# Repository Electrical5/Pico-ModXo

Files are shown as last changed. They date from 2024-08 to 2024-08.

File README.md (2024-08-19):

# Pi Pico modchip adapter for Original Xbox

This version is based on the ['V1 version'](https://github.com/Team-Resurgent/Modxo) by Team Resurgent (including Shalx)

See the [V0.2 release](https://github.com/Electrical5/Pico-ModXo/releases/tag/V0.2) for the support of the original "[ModXo](https://github.com/shalxmva/modxo)" by Shalx

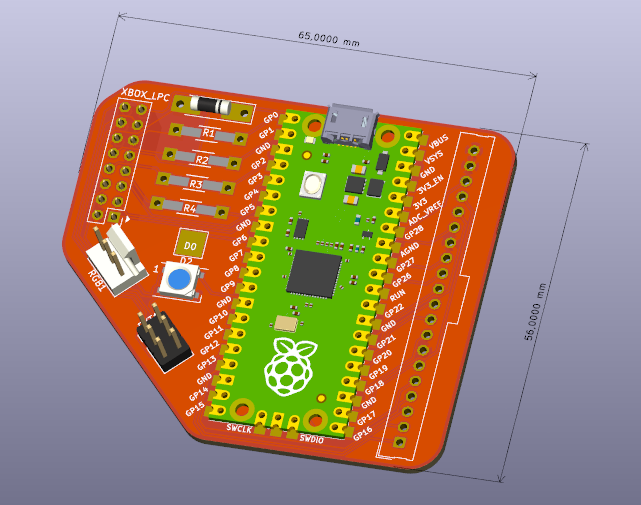
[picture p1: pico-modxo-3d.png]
3d


# Easy to solder

All components can be soldered 'though hole' at home and the Pico/resistors also have 'surface mount' options, making it ideal for hobbyists or mass production.

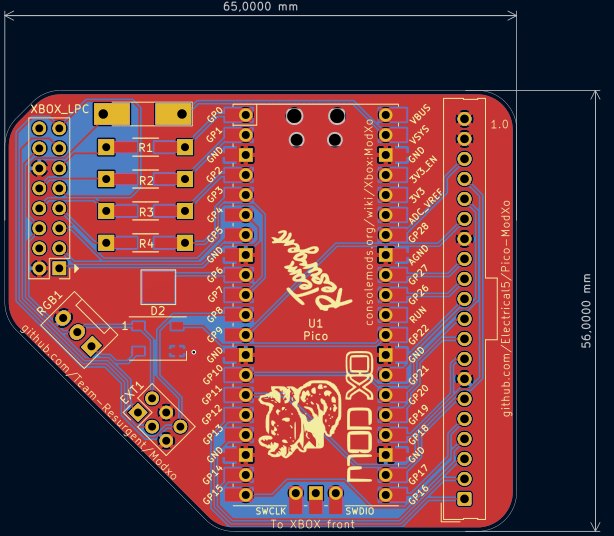
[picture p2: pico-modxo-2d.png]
2d


# Fully open source

The KiCad (free application) source files (full schematics!) are included, so you can add/remove components based on your preferences.

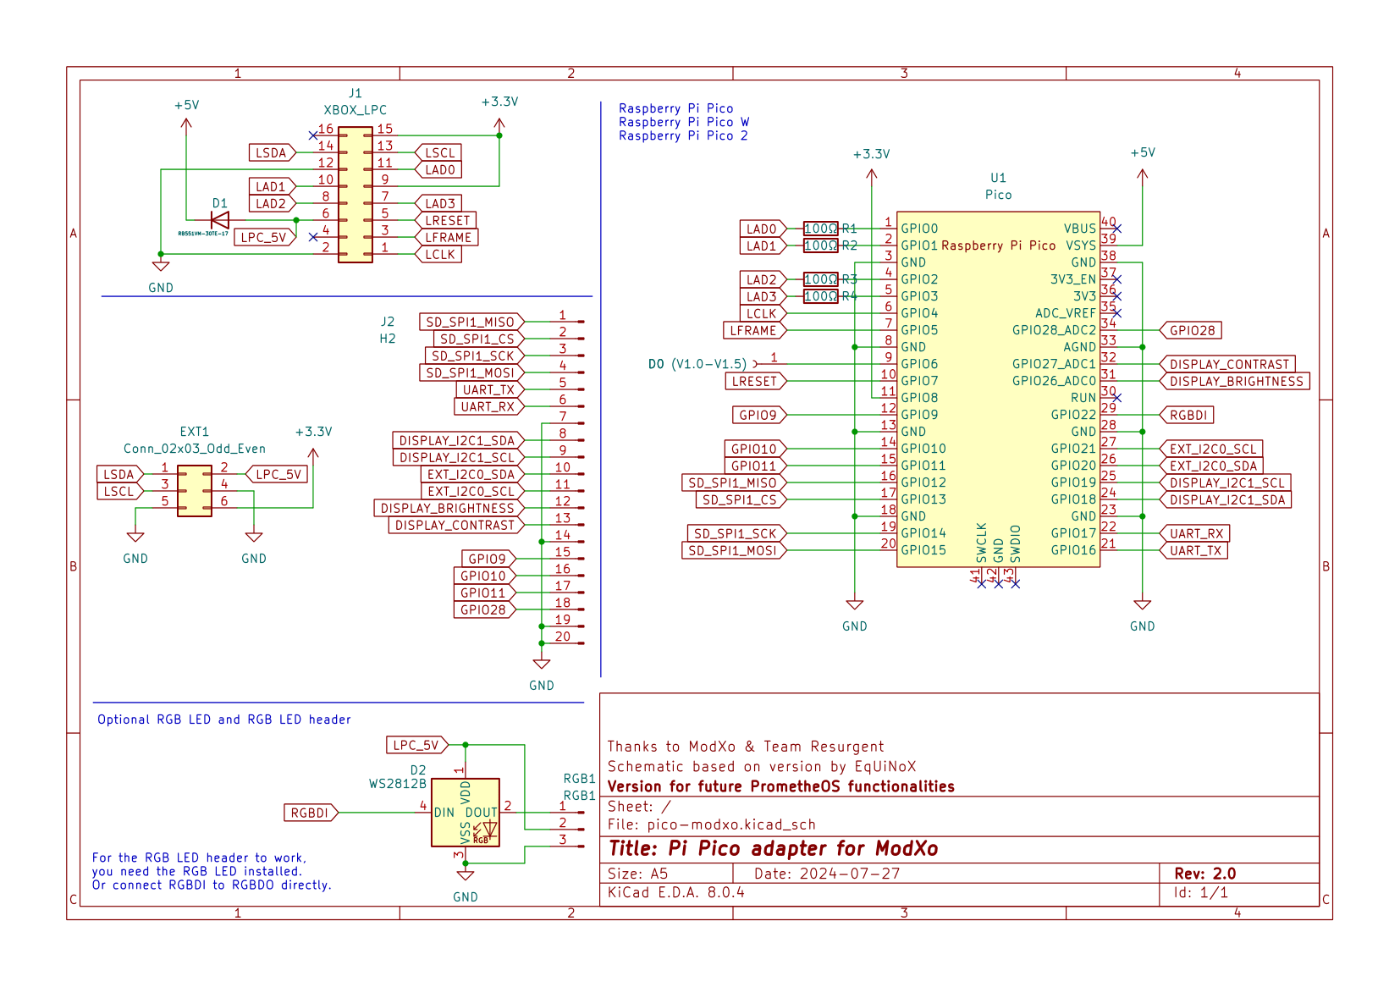
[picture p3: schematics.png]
schematics


# SMBus

Currently ModXo doesn't implement reading SMBus via I2C, in the future this could add functionality such as monitoring temperature/fanspeed, LED control or restarting/shutdown the xbox remotely.
Especially if paired with the Pi Pico Wireless, it could allow basic remote control / monitoring of the xbox.
However, there's two solder jumpers to connect the SMBus of the Xbox to the Pi Pico.

# License

GNU GENERAL PUBLIC LICENSE
Version 3, 29 June 2007

You can sell this board as-is, but disclose the source.
If you sell modifications of this board (additional headers for LED strips / LCD / fan), share the modifications / source files under the same license.

# More info

https://github.com/shalxmva/modxo
https://consolemods.org/wiki/Xbox:ModXo

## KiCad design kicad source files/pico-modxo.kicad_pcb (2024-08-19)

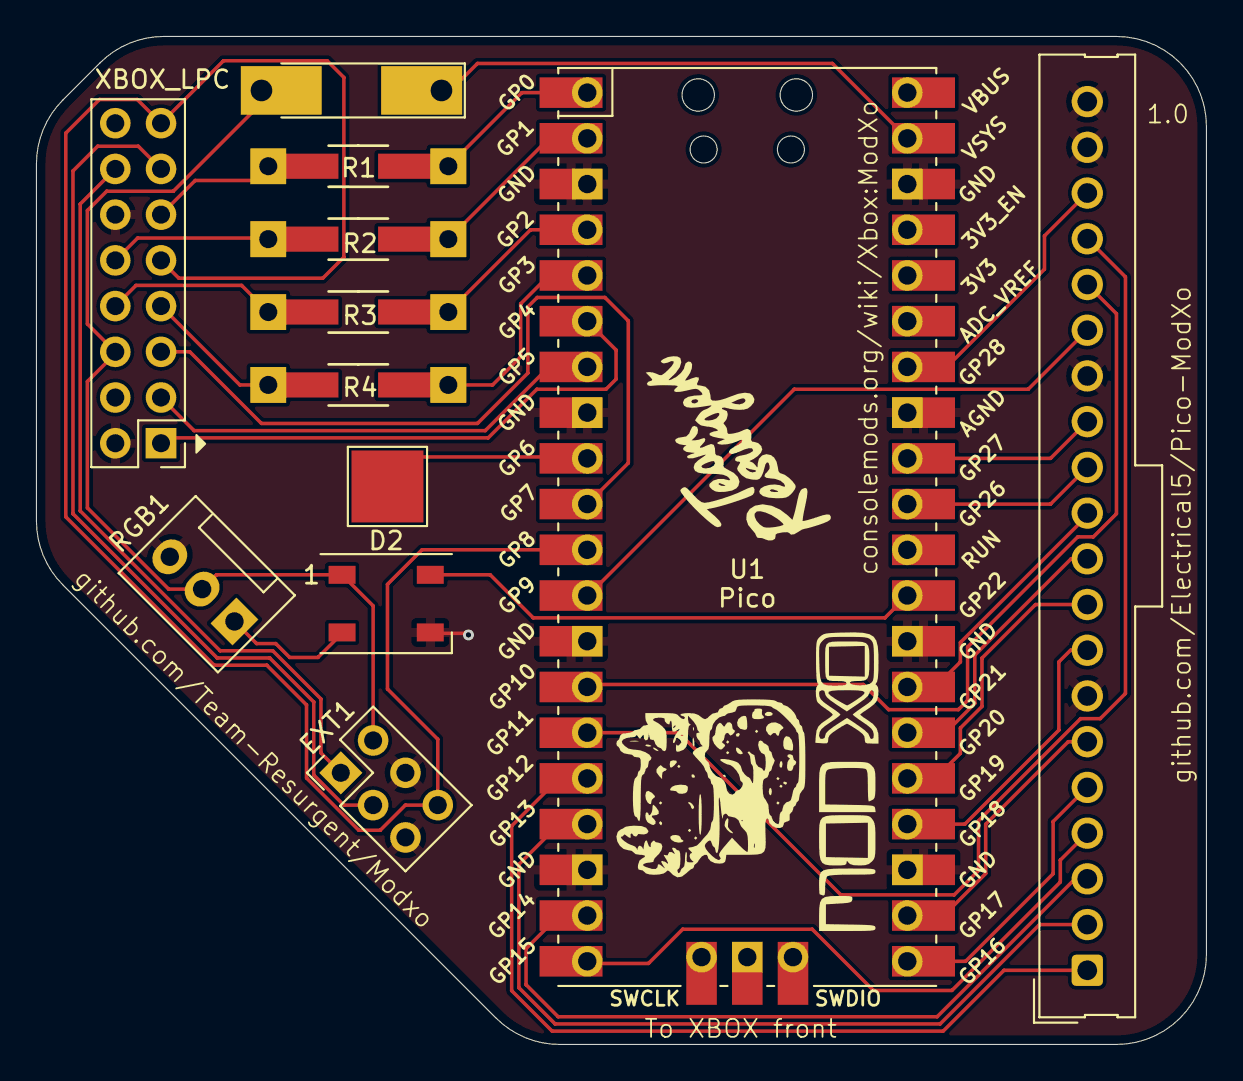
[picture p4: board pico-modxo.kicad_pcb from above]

Board: 2 copper layers, 65.0 x 56.0 mm, 12 parts (0 on the bottom side), 36 nets.

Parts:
D0: D0 (V1.0-V1.5); TestPoint_Pad_4.0x4.0mm
D1: RB551VM-30TE-17; D_MELF-RM10_Universal_Handsoldering
D2: WS2812B; LED_WS2812B_PLCC4_5.0x5.0mm_P3.2mm
EXT1: Conn_02x03_Odd_Even; PinHeader_2x03_P2.54mm_Vertical
J1: XBOX_LPC; xbox_lpc
J2: H2; Molex_SL_171971-0020_1x20_P2.54mm_Vertical
R1, R2, R3, R4: 100Ω; Resistor_SMD+THTuniversal_1206_RM10_HandSoldering
RGB1: RGB1; FanPinHeader_1x03_P2.54mm_Vertical
U1: Pico; RPi_Pico_SMD_TH

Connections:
+3.3V: EXT1.6, J1.9 (3.3V), J1.15 (3.3V), U1.11 (GPIO8)
+5V: D1.1 (K), U1.39 (VSYS)
DISPLAY_BRIGHTNESS: J2.12, U1.31 (GPIO26_ADC0)
DISPLAY_CONTRAST: J2.13, U1.32 (GPIO27_ADC1)
DISPLAY_I2C1_SCL: J2.9, U1.25 (GPIO19)
DISPLAY_I2C1_SDA: J2.8, U1.24 (GPIO18)
EXT_I2C0_SCL: J2.11, U1.27 (GPIO21)
EXT_I2C0_SDA: J2.10, U1.26 (GPIO20)
GND: D2.3 (VSS), EXT1.4, EXT1.5, J1.2 (GND), J1.12 (GND), J2.7, J2.14, J2.19, J2.20, RGB1.3, U1.3 (GND), U1.8 (GND), U1.13 (GND), U1.18 (GND), U1.23 (GND), U1.28 (GND), U1.33 (AGND), U1.38 (GND)
GPIO9: J2.15, U1.12 (GPIO9)
GPIO10: J2.16, U1.14 (GPIO10)
GPIO11: J2.17, U1.15 (GPIO11)
GPIO28: J2.18, U1.34 (GPIO28_ADC2)
LAD0: J1.11 (LAD0), R1.1
LAD1: J1.10 (LAD1), R2.1
LAD2: J1.8 (LAD2), R3.1
LAD3: J1.7 (LAD3), R4.1
LCLK: J1.1 (LCLK), U1.6 (GPIO4)
LFRAME: J1.3 (LFRAME#), U1.7 (GPIO5)
LPC_5V: D1.2 (A), D2.1 (VDD), EXT1.2, J1.6 (5V), RGB1.2
LRESET: J1.5 (LRESET#), U1.10 (GPIO7)
LSCL: EXT1.3, J1.13 (SCL)
LSDA: EXT1.1, J1.14 (SDA)
unnamed: D0.1, U1.9 (GPIO6)
unnamed: D2.2 (DOUT), RGB1.1
unnamed: R1.2, U1.1 (GPIO0)
unnamed: R2.2, U1.2 (GPIO1)
unnamed: R3.2, U1.4 (GPIO2)
unnamed: R4.2, U1.5 (GPIO3)
RGBDI: D2.4 (DIN), U1.29 (GPIO22)
SD_SPI1_CS: J2.2, U1.17 (GPIO13)
SD_SPI1_MISO: J2.1, U1.16 (GPIO12)
SD_SPI1_MOSI: J2.4, U1.20 (GPIO15)
SD_SPI1_SCK: J2.3, U1.19 (GPIO14)
UART_RX: J2.6, U1.22 (GPIO17)
UART_TX: J2.5, U1.21 (GPIO16)

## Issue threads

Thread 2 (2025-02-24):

How to connect a screen to the pcb?

MrPretus, 2025-02-24:
I have tried to figure out how to connect a screen through this pcb, but I don't quite understand how to do it. If I understand correctly, it must be interconnected through the ext port?

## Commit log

2024-07-28 Initial commit
    Initial commit
    [pico-modxo-B_Cu.gbr, pico-modxo-B_Mask.gbr, pico-modxo-B_Paste.gbr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]
2024-07-28 Added schematics
2024-08-18 V2 Design
    V2 Design based on EqUiNoX schematic 1.0 2024-07-29
    [pico-modxo-B_Cu.gbr, pico-modxo-B_Mask.gbr, pico-modxo-B_Paste.gbr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]
2024-08-18 Updated board to V2
    See old 'V1' branch for original.
    This V2 branch has suppport for LED / GPIO etc.
    [pico-modxo-B_Cu.gbr, pico-modxo-B_Mask.gbr, pico-modxo-B_Paste.gbr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]
2024-08-19 Move GND add GP8
    added Gp8 connected to 3.3v
    moved GND to bottom.
    [pico-modxo.kicad_pcb, pico-modxo.kicad_sch]
2024-08-19 RGB LED GND via
    added via to Grad plain for RGB LED
    [pico-modxo.kicad_pcb]
2024-08-19 Pico ModXo V1.0
    Release V1.0
    [pico-modxo-B_Cu.gbr, pico-modxo-B_Mask.gbr, pico-modxo-B_Paste.gbr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]
